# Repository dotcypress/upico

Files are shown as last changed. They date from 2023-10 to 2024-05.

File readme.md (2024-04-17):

## μPico

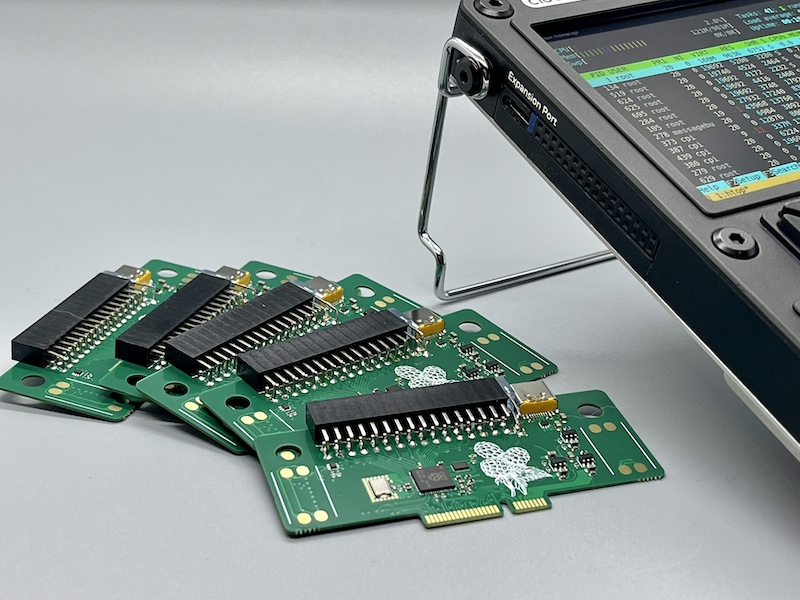
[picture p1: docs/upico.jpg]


### What is it?

uPico is a [RP2040](https://www.raspberrypi.com/products/rp2040/) powered expansion card designed to enhance the capabilities of [Clockwork's uConsole](https://www.clockworkpi.com/uconsole).

⚠️ Only R-01 and CM4 core are supported by control application.
Work in progress for A04/A06 core modules.

Second project name is `atto`, cause 10<sup>−6</sup> * 10<sup>-12</sup> = 10<sup>-18</sup> 🤓

### Features

* Internal Speakers Support
* Type-C (USB 2.0) port with programmable power switch and overcurrent protection
* 3.3V and 5V external power out with programmable switch and overcurrent protection
* RP2040 with extenal double-double PMOD compatible connector
* RP2040 controllable LED

## Resources

- [Schematics](docs/upico.pdf)
- [PCB Viewer](https://kicanvas.org/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)
- [Interactive BOM](https://htmlpreview.github.io/?https://github.com/dotcypress/upico/blob/main/docs/ibom.html)



### Control app installation

1. Download latest build from [Releases page](https://github.com/dotcypress/upico/releases)
2. Extract installer: `mkdir dist && tar -xzf upico_%version%.%core%.tar.gz -C dist`
3. Install: `cd dist && sudo ./install.sh`
4. Cleanup: `cd .. && rm -rf dist`
5. Print help: `upico help`

### Building control app from sources

1. Install rustup by following the instructions at https://rustup.rs
2. Clone this repo: `git clone git@github.com:dotcypress/upico.git && cd upico`
3. Build: `cargo build --release`
4. Install app: `sudo cp target/release/upico /usr/local/bin/`
5. Install service: `sudo cp upico.service /etc/systemd/system/`
6. Enable service: `sudo systemctl enable upico`
7. Start service: `sudo systemctl start upico`
8. Setup uPico extender USB device: `echo 'SUBSYSTEM=="usb",ATTRS{idVendor}=="1209",ATTRS{idProduct}=="bc07",MODE="0660",GROUP="plugdev"' > /etc/udev/rules.d/50-upico-permissions.rules`
9. Reload udev: `udevadm control --reload-rules`
10. Print help: `upico help`

### Flash firmware

1. `wget https://rptl.io/pico-blink`
2. `upico install pico-blink` or `upico install -m pico-blink` if automount is disabled for hot-plug devices.

See other examples: https://github.com/raspberrypi/pico-examples

### High level design diagram

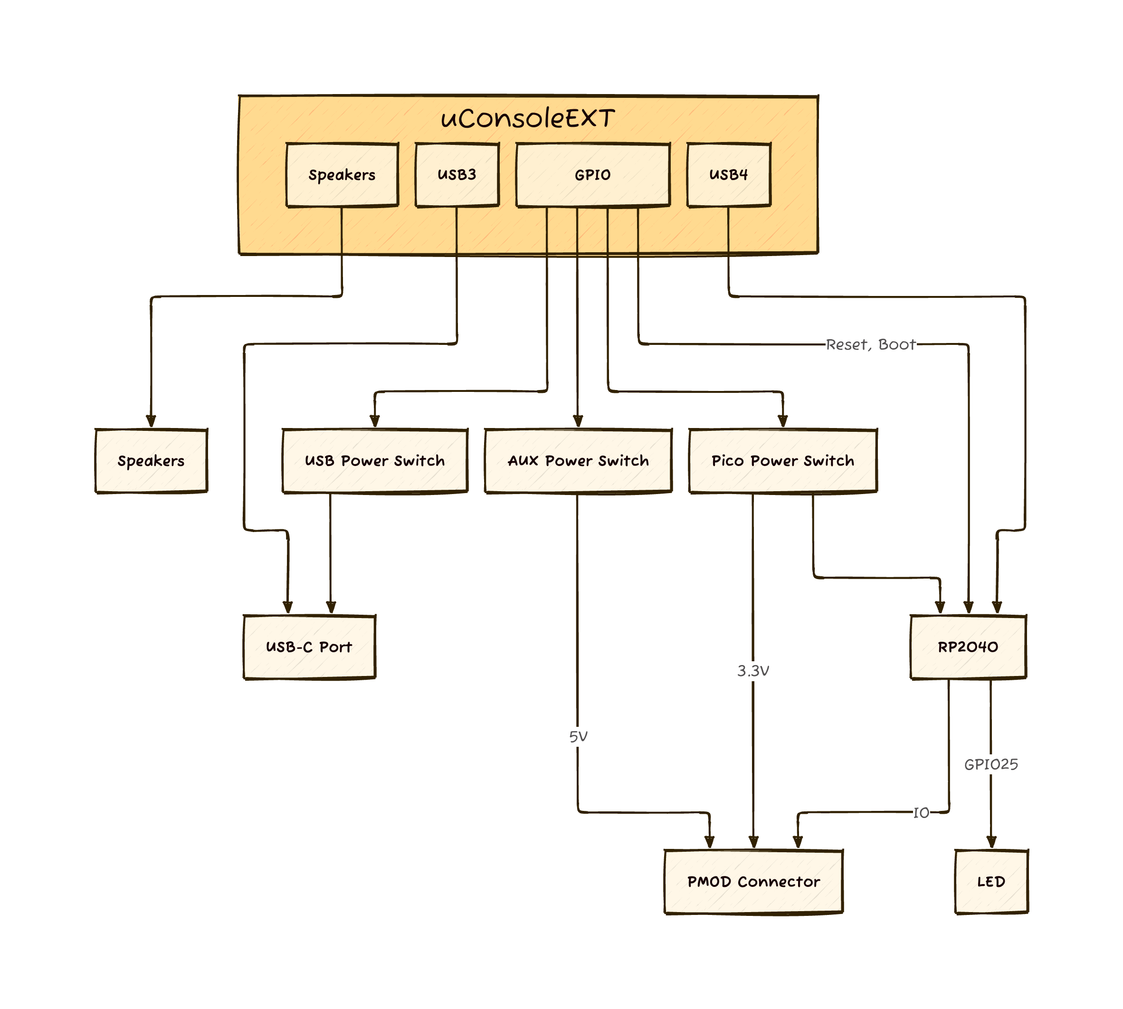
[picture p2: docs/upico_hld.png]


### GPIO Header Pinout
```
╔══════╦══════╗
║ AUX  ║ AUX  ║
╠══════╬══════╣
║ VDD  ║ VDD  ║
║ GND  ║ GND  ║
║ IO3  ║ IO7  ║
║ IO2  ║ IO6  ║
║ IO1  ║ IO5  ║
║ IO0  ║ IO4  ║
╠══════╬══════╣
║ IO27 ║ IO29 ║
║ IO26 ║ IO28 ║
║ IO18 ║ IO19 ║
╠══════╬══════╣
║ VDD  ║ VDD  ║
║ GND  ║ GND  ║
║ IO11 ║ IO15 ║
║ IO10 ║ IO14 ║
║ IO9  ║ IO13 ║
║ IO8  ║ IO12 ║
╚══════╩══════╝
```

## Errata

### CM4 core & uPico PCB rev:0x02

* Overcurrent reporting feature isn't supported.

## License

Licensed under either of

- Apache License, Version 2.0 ([LICENSE-APACHE](LICENSE-APACHE) or
  http://www.apache.org/licenses/LICENSE-2.0)
- MIT license ([LICENSE-MIT](LICENSE-MIT) or http://opensource.org/licenses/MIT)

at your option.

### Contribution

Unless you explicitly state otherwise, any contribution intentionally submitted
for inclusion in the work by you, as defined in the Apache-2.0 license, shall be
dual licensed as above, without any additional terms or conditions.

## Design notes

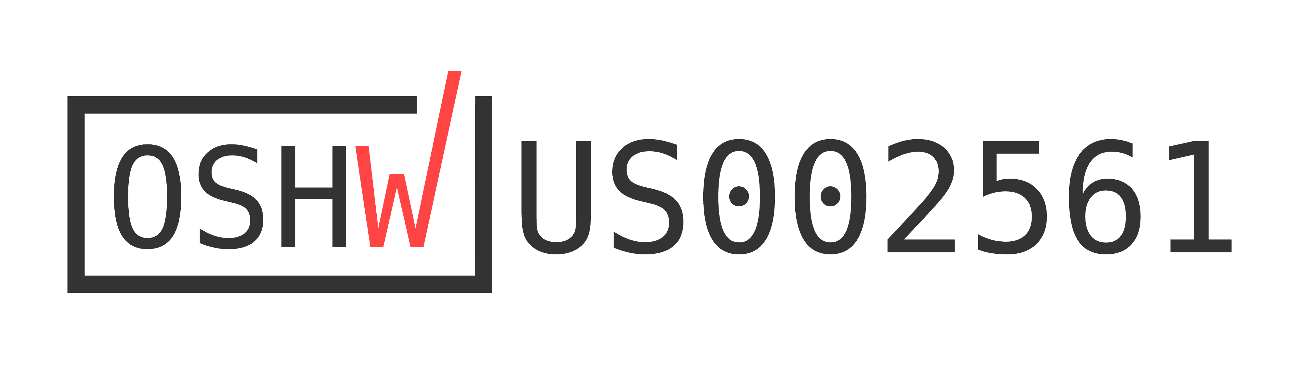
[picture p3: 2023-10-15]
docs/certification-mark-US002561.png

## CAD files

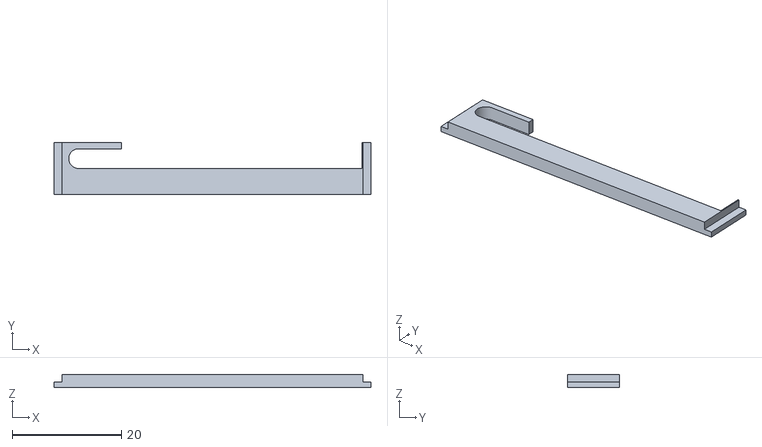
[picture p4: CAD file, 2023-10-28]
docs/cover.stl
58.0 x 9.50 x 2.40

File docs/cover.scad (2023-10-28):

$fn=128;
epsilon=0.01;

module cover() {
  difference() {
    union() {
      cube(size=[58, 9.5, 1], center=true);
      translate([0, 0, 1])
        cube(size=[55, 9.5, 1.8], center=true);
    }

    translate([5.3+epsilon, 2.5+epsilon, 0]) 
      cube(size=[44, 5, 20], center=true);

    translate([-24.5, 1.8, 0]) hull() {
      cylinder(r=1.8, h=20, center=true);
      translate([10, 0, 0])
        cylinder(r=1.8, h=20, center=true);
    }
  }
}

module print() {
  translate([0, 4, 0.5]) 
    cube(size=[1, 88, 1], center=true);
  for (i=[-3:4]) {
    translate([0, i*12, 0.6]) cover();
  }
}

// print();
cover();

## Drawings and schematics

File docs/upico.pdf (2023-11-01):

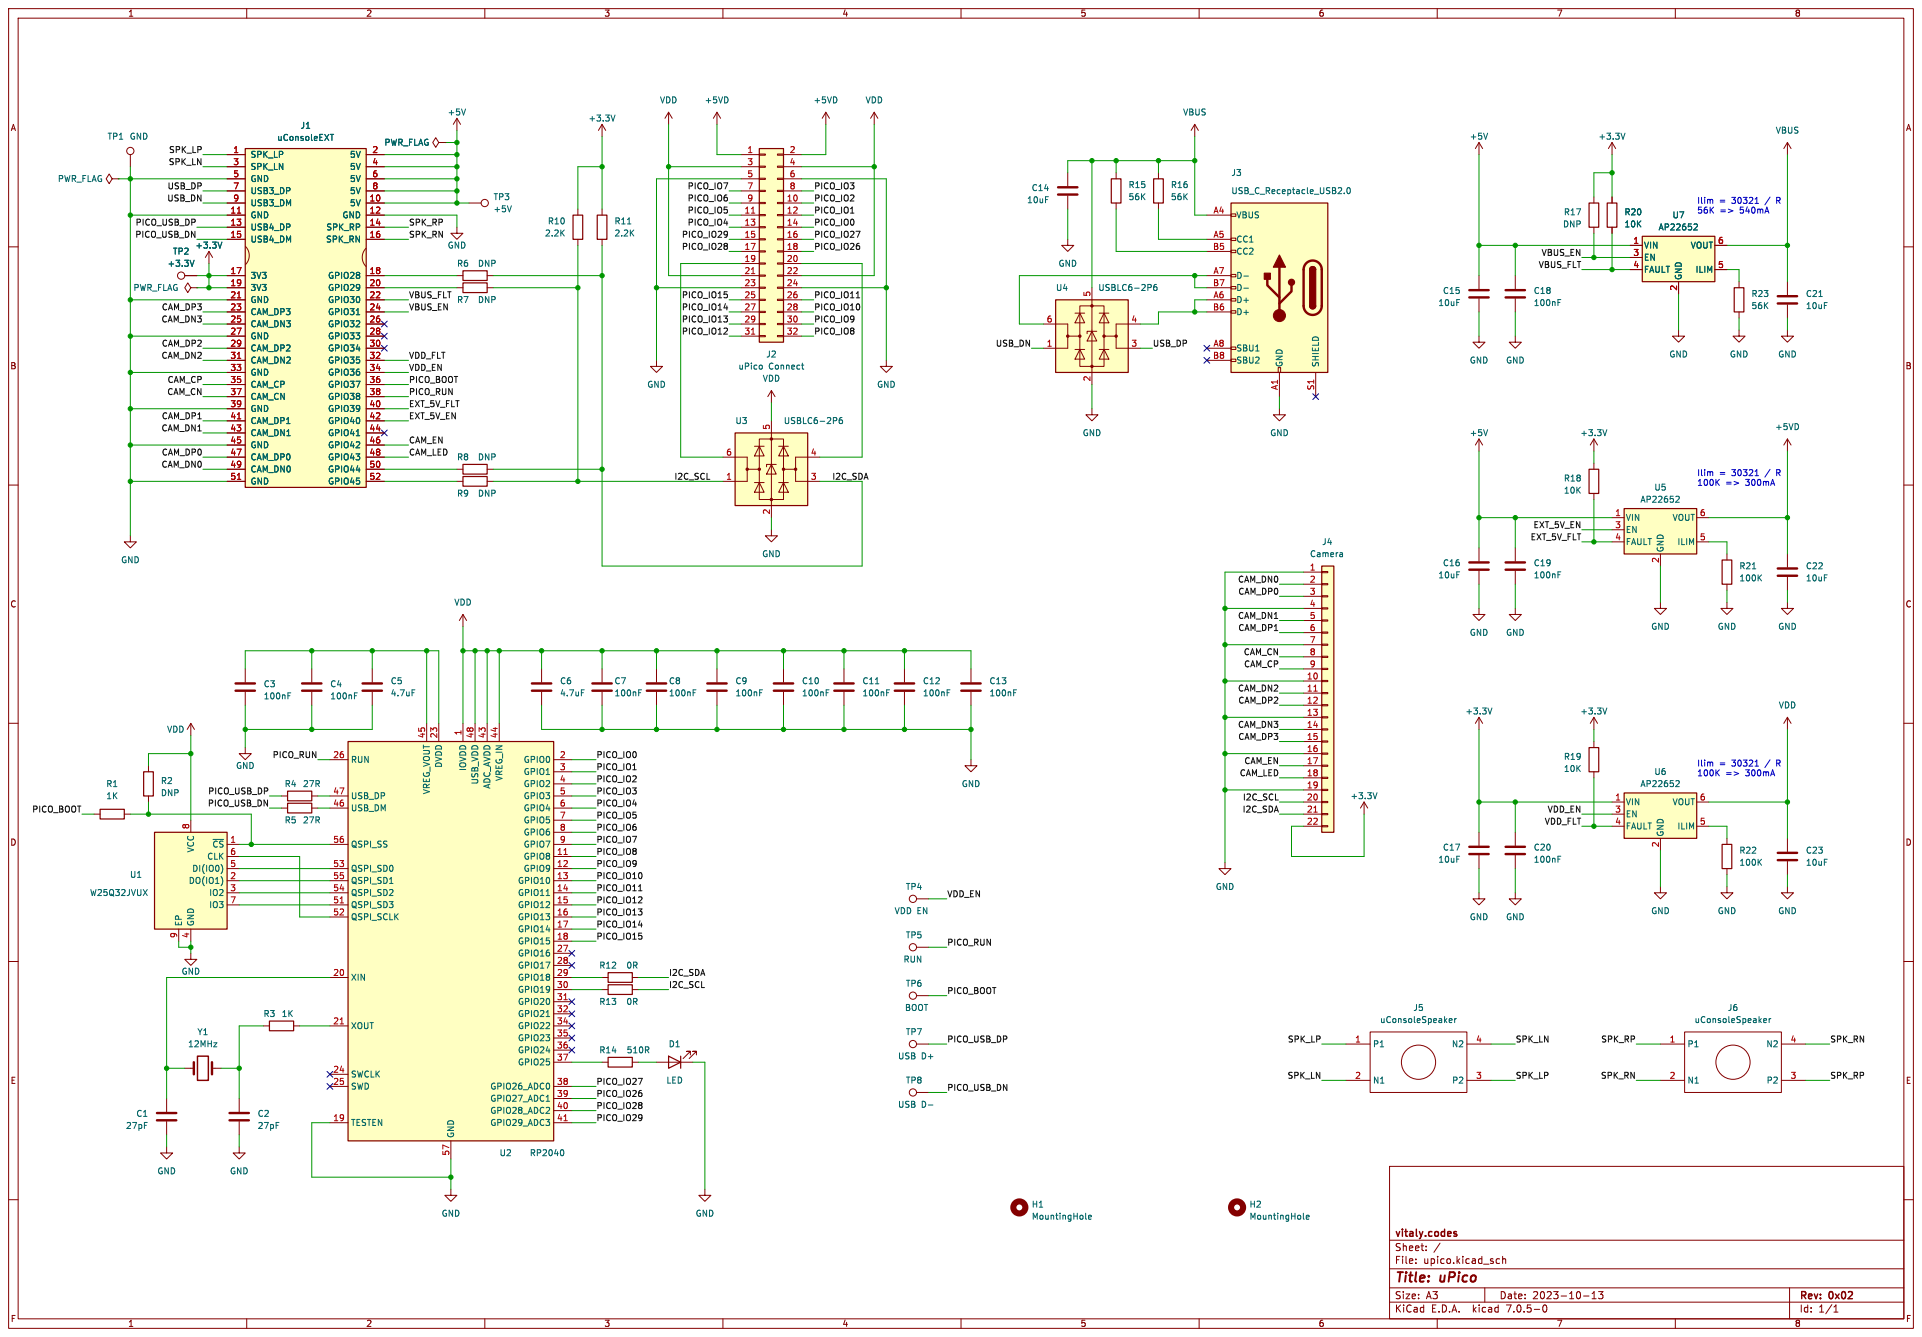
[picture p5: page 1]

1 GPIO8 11 GPIO9 12 GPIO10 13 GPIO11 14 GPIO12 15 GPIO13 16 GPIO14 17 GPIO15 18 TESTEN 19 GPIO0 2 XIN 20 XOUT 21 DVDD 23 SWCLK 24 SWD 25 RUN 26 GPIO16 27 GPIO17 28 GPIO18 29 GPIO1 3 GPIO19 30 GPIO20 31 GPIO21 32 GPIO22 34 GPIO23 35 GPIO24 36 GPIO25 37 GPIO26_ADC0 38 GPIO27_ADC1 39 GPIO2 4 GPIO28_ADC2 40 GPIO29_ADC3 41 ADC_AVDD 43 VREG_IN 44 VREG_VOUT 45 USB_DM 46 USB_DP 47 USB_VDD 48 GPIO3 5 QSPI_SD3 51 QSPI_SCLK 52 QSPI_SD0 53 QSPI_SD2 54 QSPI_SD1 55 QSPI_SS 56 GND 57 GPIO4 6 GPIO5 7 GPIO6 8 GPIO7 9 U2 RP2040

H1 MountingHole TP7 USB D+ TP8 USB D- TP5 RUN

File: upico.kicad_sch Sheet: / vitaly.codes

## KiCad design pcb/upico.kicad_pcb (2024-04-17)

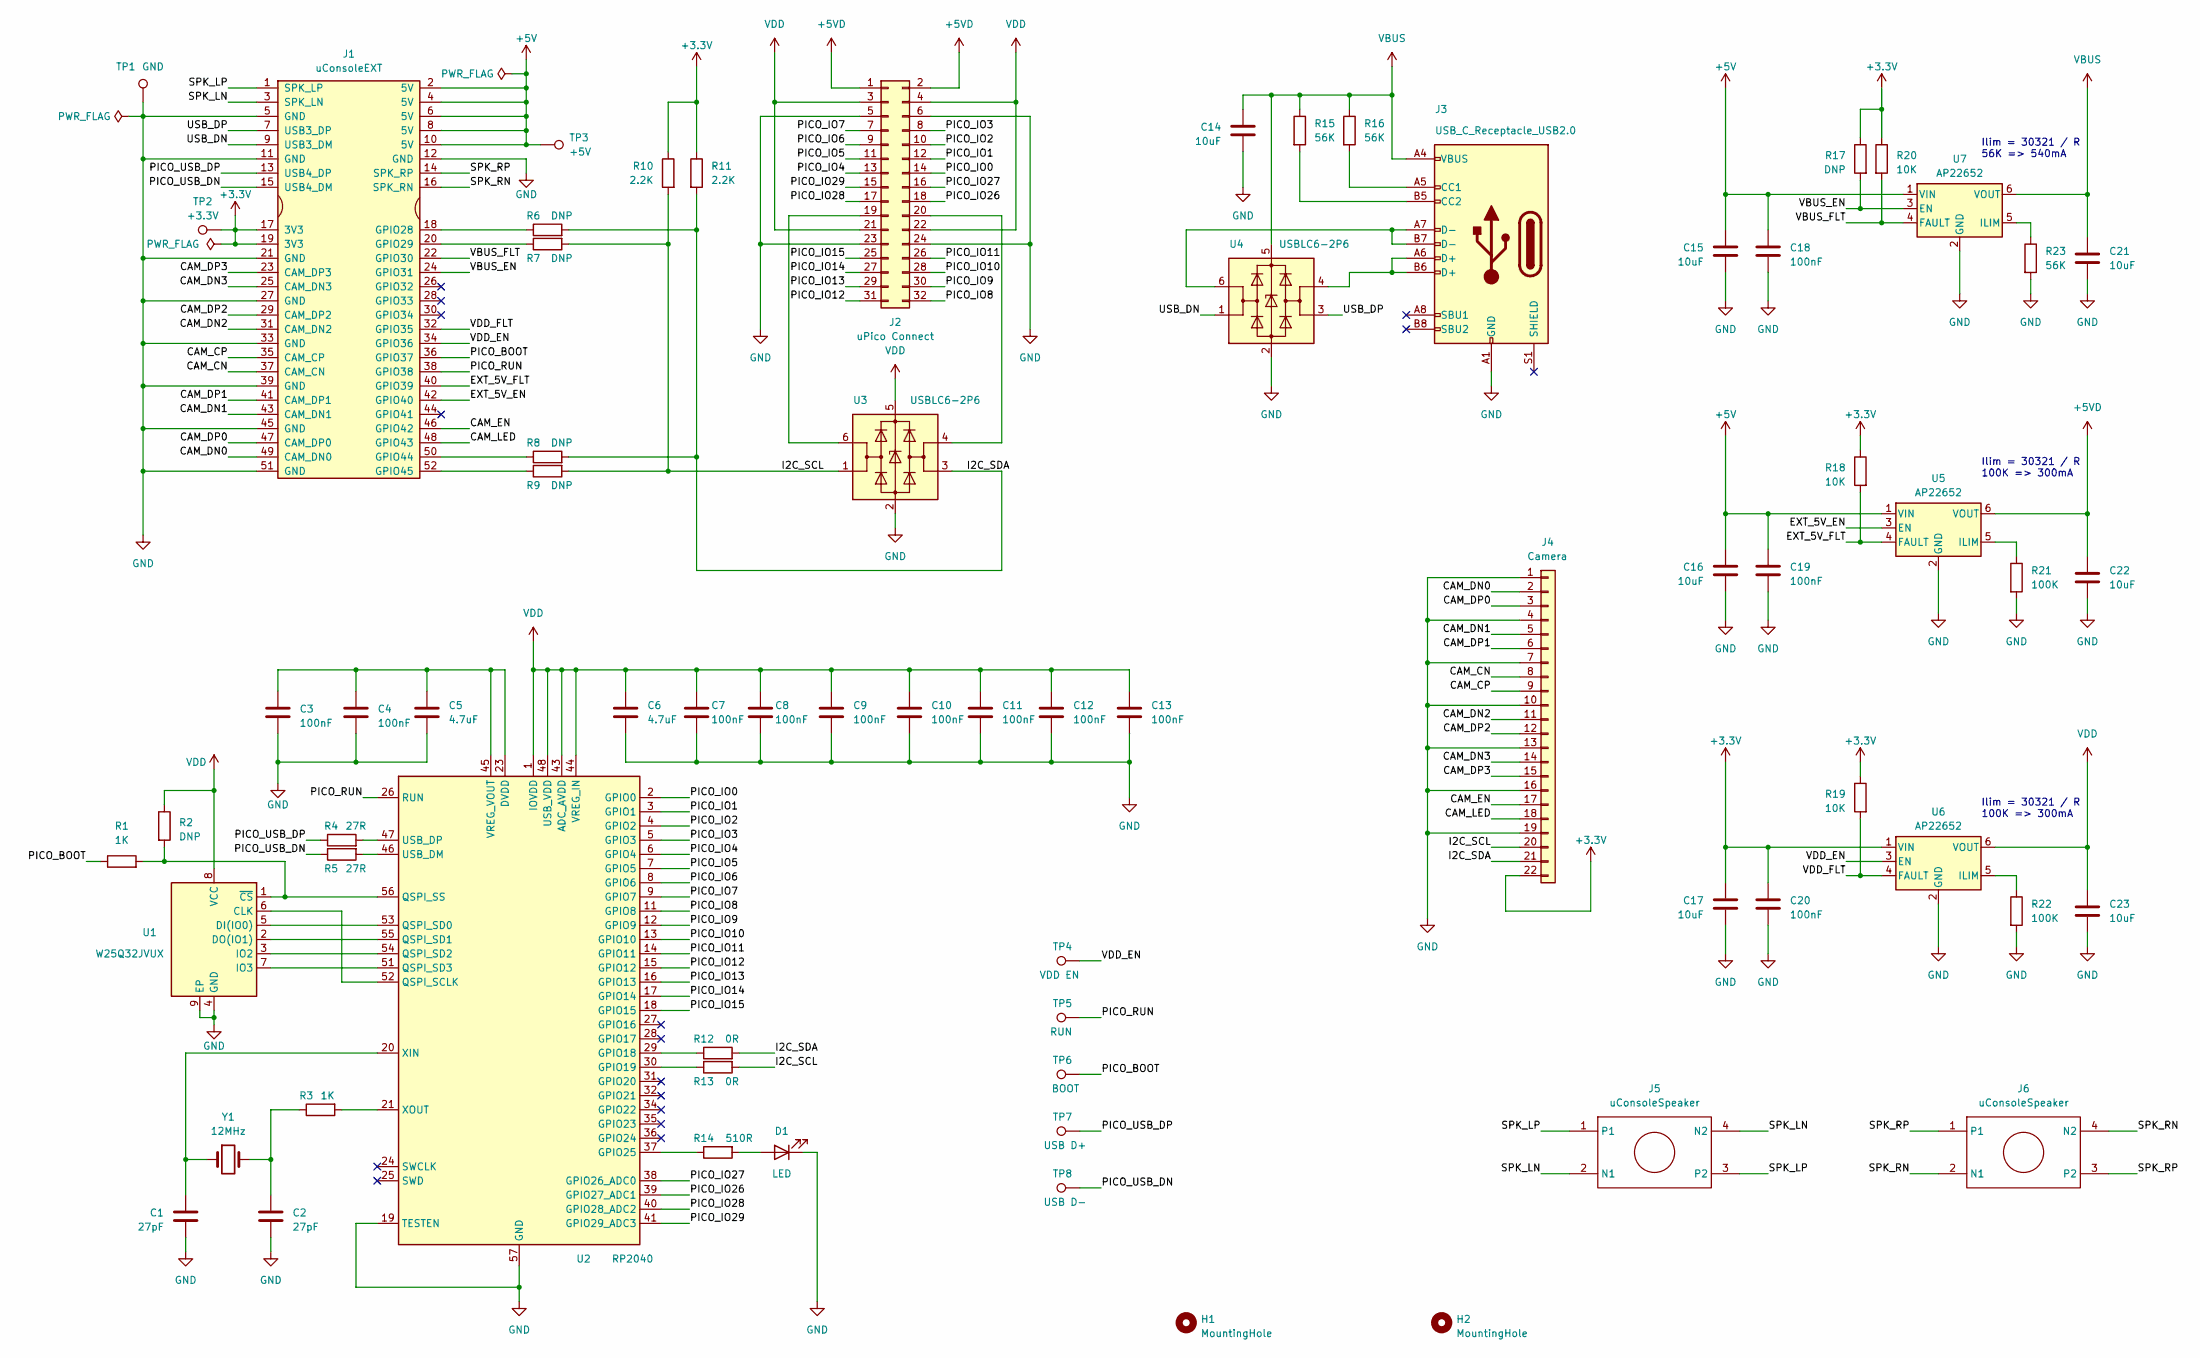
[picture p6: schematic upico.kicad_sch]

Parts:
C1, C2: 27pF; C_0402_1005Metric
C3, C4, C7, C8, C9, C10, C11, C12, C13, C18, C19, C20: 100nF; C_0402_1005Metric
C5, C6: 4.7uF; C_0402_1005Metric
C14, C15, C16, C17, C21, C22, C23: 10uF; C_0603_1608Metric
D1: LED; LED_SideEmitter_Rectangular_W4.5mm_H1.6mm
H1, H2: MountingHole; MountingHole_5.3mm_M5
J1: uConsoleEXT; ext
J2: uPico Connect; PinSocket_2x16_P2.54mm_Horizontal
J3: USB_C_Receptacle_USB2.0; USB_C_Receptacle_HRO_TYPE-C-31-M-12
J4: Camera; Hirose_FH12-22S-0.5SH_1x22-1MP_P0.50mm_Horizontal
J5, J6: uConsoleSpeaker; speaker
R1, R3: 1K; R_0402_1005Metric
R2, R6, R7, R8, R9, R17: DNP; R_0402_1005Metric
R4, R5: 27R; R_0402_1005Metric
R10, R11: 2.2K; R_0402_1005Metric
R12, R13: 0R; R_0402_1005Metric
R14: 510R; R_0402_1005Metric
R15, R16, R23: 56K; R_0402_1005Metric
R18, R19, R20: 10K; R_0402_1005Metric
R21, R22: 100K; R_0402_1005Metric
TP1: GND; TestPoint_Pad_D1.0mm
TP2: +3.3V; TestPoint_Pad_D1.0mm
TP3: +5V; TestPoint_Pad_D1.0mm
TP4: VDD EN; TestPoint_Pad_D1.0mm
TP5: RUN; TestPoint_Pad_D1.0mm
TP6: BOOT; TestPoint_Pad_D1.0mm
TP7: USB D+; TestPoint_Pad_D1.0mm
TP8: USB D-; TestPoint_Pad_D1.0mm
U1: W25Q32JVUX; USON-8_2x3mm_P0.5mm
U2: RP2040; QFN-56-1EP_7x7mm_P0.4mm_EP3.2x3.2mm
U3, U4: USBLC6-2P6; SOT-666
U5, U6, U7: AP22652; SOT-23-6
Y1: 12MHz; Crystal_SMD_5032-2Pin_5.0x3.2mm

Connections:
+3.3V: C17.2, C20.2, J1.17 (3V3), J1.19 (3V3), J4.22, R10.1, R11.1, R17.1, R18.1, R19.1, R20.1, TP2.1, U6.1 (VIN)
+5V: C15.2, C16.2, C18.2, C19.2, J1.2 (5V), J1.4 (5V), J1.6 (5V), J1.8 (5V), J1.10 (5V), TP3.1, U5.1 (VIN), U7.1 (VIN)
+5VD: C22.1, J2.1, J2.2, U5.6 (VOUT)
/CAM_CN: J1.37 (CAM_CN), J4.8
/CAM_CP: J1.35 (CAM_CP), J4.9
/CAM_DN0: J1.49 (CAM_DN0), J4.2
/CAM_DN1: J1.43 (CAM_DN1), J4.5
/CAM_DN2: J1.31 (CAM_DN2), J4.11
/CAM_DN3: J1.25 (CAM_DN3), J4.14
/CAM_DP0: J1.47 (CAM_DP0), J4.3
/CAM_DP1: J1.41 (CAM_DP1), J4.6
/CAM_DP2: J1.29 (CAM_DP2), J4.12
/CAM_DP3: J1.23 (CAM_DP3), J4.15
/CAM_EN: J1.46 (GPIO42), J4.17
/CAM_LED: J1.48 (GPIO43), J4.18
/EXT_5V_EN: J1.42 (GPIO40), U5.3 (EN)
/EXT_5V_FLT: J1.40 (GPIO39), R18.2, U5.4 (FAULT)
/I2C_SCL: J4.20, R7.2, R9.2, R10.2, R13.2, U3.1 (I/O1)
/I2C_SDA: J4.21, R6.2, R8.2, R11.2, R12.2, U3.3 (I/O2)
/PICO_BOOT: J1.36 (GPIO37), R1.1, TP6.1
/PICO_IO0: J2.14, U2.2 (GPIO0)
/PICO_IO1: J2.12, U2.3 (GPIO1)
/PICO_IO2: J2.10, U2.4 (GPIO2)
/PICO_IO3: J2.8, U2.5 (GPIO3)
/PICO_IO4: J2.13, U2.6 (GPIO4)
/PICO_IO5: J2.11, U2.7 (GPIO5)
/PICO_IO6: J2.9, U2.8 (GPIO6)
/PICO_IO7: J2.7, U2.9 (GPIO7)
/PICO_IO8: J2.32, U2.11 (GPIO8)
/PICO_IO9: J2.30, U2.12 (GPIO9)
/PICO_IO10: J2.28, U2.13 (GPIO10)
/PICO_IO11: J2.26, U2.14 (GPIO11)
/PICO_IO12: J2.31, U2.15 (GPIO12)
/PICO_IO13: J2.29, U2.16 (GPIO13)
/PICO_IO14: J2.27, U2.17 (GPIO14)
/PICO_IO15: J2.25, U2.18 (GPIO15)
/PICO_IO26: J2.18, U2.39 (GPIO27_ADC1)
/PICO_IO27: J2.16, U2.38 (GPIO26_ADC0)
/PICO_IO28: J2.17, U2.40 (GPIO28_ADC2)
/PICO_IO29: J2.15, U2.41 (GPIO29_ADC3)
/PICO_RUN: J1.38 (GPIO38), TP5.1, U2.26 (RUN)
/PICO_USB_DN: J1.15 (USB4_DM), R5.1, TP8.1
/PICO_USB_DP: J1.13 (USB4_DP), R4.1, TP7.1
/SPK_LN: J1.3 (SPK_LN), J5.2 (N1), J5.4 (N2)
/SPK_LP: J1.1 (SPK_LP), J5.1, J5.3 (P2)
/SPK_RN: J1.16 (SPK_RN), J6.2 (N1), J6.4 (N2)
/SPK_RP: J1.14 (SPK_RP), J6.1, J6.3 (P2)
/USB_DN: J1.9 (USB3_DM), U4.1 (I/O1)
/USB_DP: J1.7 (USB3_DP), U4.3 (I/O2)
/VBUS_EN: J1.24 (GPIO31), R17.2, U7.3 (EN)
/VBUS_FLT: J1.22 (GPIO30), R20.2, U7.4 (FAULT)
/VDD_EN: J1.34 (GPIO36), TP4.1, U6.3 (EN)
/VDD_FLT: J1.32 (GPIO35), R19.2, U6.4 (FAULT)
GND: C1.2, C2.2, C3.2, C4.2, C5.2, C6.2, C7.2, C8.2, C9.2, C10.2, C11.2, C12.2, C13.2, C14.1, C15.1, C16.1, C17.1, C18.1, C19.1, C20.1, C21.2, C22.2, C23.2, D1.1 (K), J1.5 (GND), J1.11 (GND), J1.12 (GND), J1.21 (GND), J1.27 (GND), J1.33 (GND), J1.39 (GND), J1.45 (GND), J1.51 (GND), J2.5, J2.6, J2.23, J2.24, J3.A1 (GND), J3.A12 (GND), J3.B1 (GND), J3.B12 (GND), J4.1, J4.4, J4.7, J4.10, J4.13, J4.16, J4.19, R21.2, R22.2, R23.2, TP1.1, U1.4 (GND), U1.9 (EP), U2.19 (TESTEN), U2.57 (GND), U3.2 (GND), U4.2 (GND), U5.2 (GND), U6.2 (GND), U7.2 (GND)
unnamed: C2.1, R3.1, Y1.2
unnamed: D1.2 (A), R14.2
unnamed: J1.18 (GPIO28), R6.1
unnamed: J1.20 (GPIO29), R7.1
unnamed: J1.50 (GPIO44), R8.1
unnamed: J1.52 (GPIO45), R9.1
unnamed: J2.19, U3.6 (I/O1)
unnamed: J2.20, U3.4 (I/O2)
unnamed: J3.A5 (CC1), R16.2
unnamed: J3.B5 (CC2), R15.2
unnamed: J3.A6 (D+), J3.B6 (D+), U4.4 (I/O2)
unnamed: J3.A7 (D-), J3.B7 (D-), U4.6 (I/O1)
unnamed: U1.6 (CLK), U2.52 (QSPI_SCLK)
unnamed: U1.5 (DI(IO0)), U2.53 (QSPI_SD0)
unnamed: U1.2 (DO(IO1)), U2.55 (QSPI_SD1)
unnamed: U1.3 (IO2), U2.54 (QSPI_SD2)
unnamed: U1.7 (IO3), U2.51 (QSPI_SD3)
unnamed: R1.2, R2.2, U1.1 (~CS), U2.56 (QSPI_SS)
unnamed: R12.1, U2.29 (GPIO18)
unnamed: R13.1, U2.30 (GPIO19)
unnamed: R14.1, U2.37 (GPIO25)
unnamed: R5.2, U2.46 (USB_DM)
unnamed: R4.2, U2.47 (USB_DP)
unnamed: C3.1, C4.1, C5.1, U2.23 (DVDD), U2.45 (VREG_VOUT), U2.50 (DVDD)
unnamed: C1.1, U2.20 (XIN), Y1.1
unnamed: R3.2, U2.21 (XOUT)
unnamed: R21.1, U5.5 (ILIM)
unnamed: R22.1, U6.5 (ILIM)
unnamed: R23.1, U7.5 (ILIM)
VBUS: C14.2, C21.1, J3.A4 (VBUS), J3.A9 (VBUS), J3.B4 (VBUS), J3.B9 (VBUS), R15.1, R16.1, U4.5 (VBUS), U7.6 (VOUT)
VDD: C6.1, C7.1, C8.1, C9.1, C10.1, C11.1, C12.1, C13.1, C23.1, J2.3, J2.4, J2.21, J2.22, R2.1, U1.8 (VCC), U2.1 (IOVDD), U2.10 (IOVDD), U2.22 (IOVDD), U2.33 (IOVDD), U2.42 (IOVDD), U2.43 (ADC_AVDD), U2.44 (VREG_IN), U2.48 (USB_VDD), U2.49 (IOVDD), U3.5 (VBUS), U6.6 (VOUT)

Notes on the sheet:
Ilim = 30321 / R 56K => 540mA
Ilim = 30321 / R 100K => 300mA

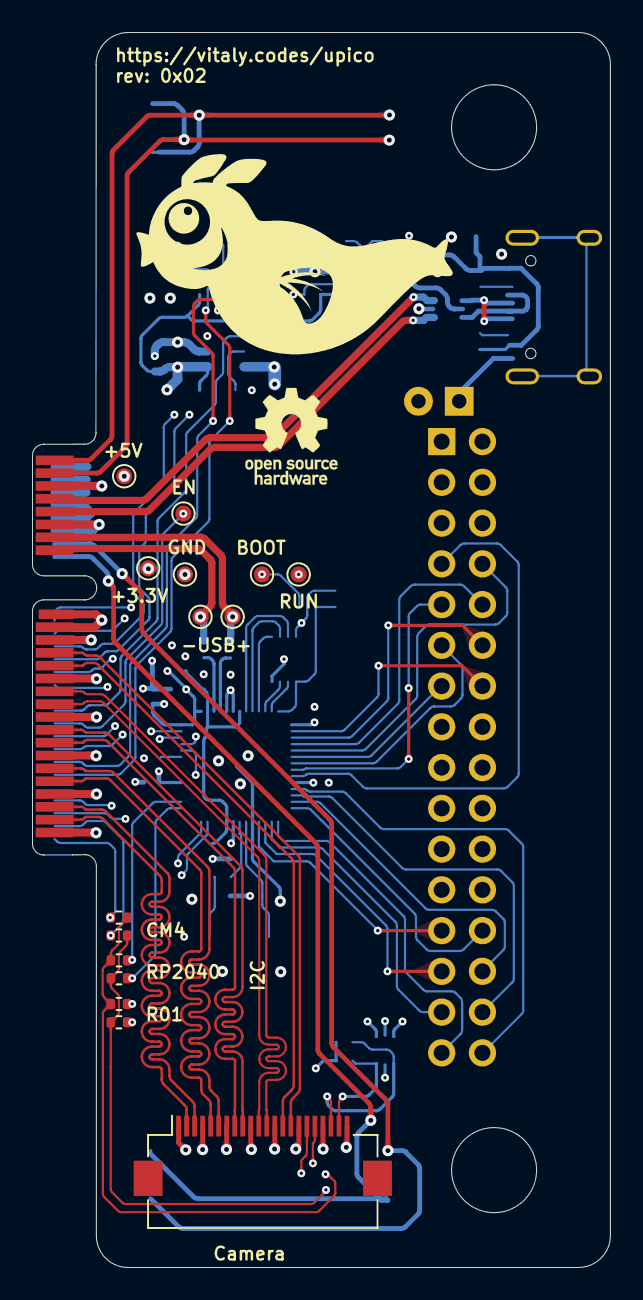
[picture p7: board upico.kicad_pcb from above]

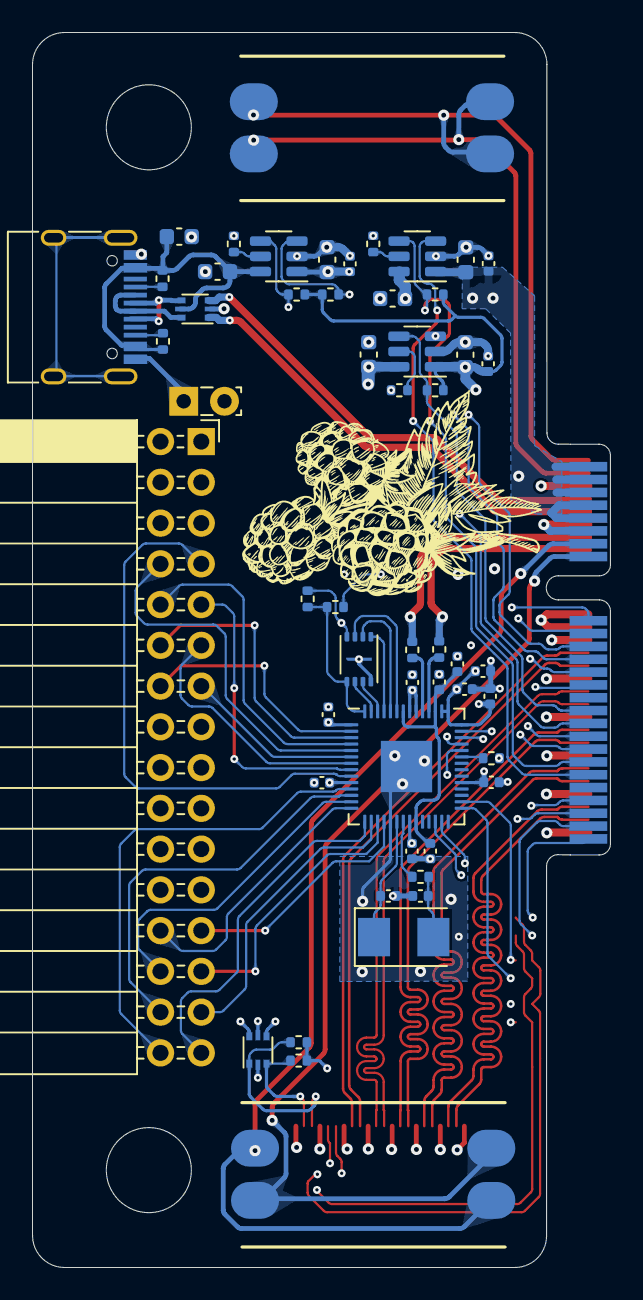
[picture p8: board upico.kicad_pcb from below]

Board: 6 copper layers, 36.0 x 77.0 mm, 71 parts (53 on the bottom side), 85 nets.

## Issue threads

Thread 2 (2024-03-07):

Internal GPIO headers?

madeofstown, 2024-03-07:
I'm sure there have to be others who would like to have an internal GPIO connection on the uPico for connecting small expansion boards that would fit inside the uConsole.

Just wanted to see if there is work being done on a new version and if others would be interested in internal GPIO pins.

I realize I could modify the board myself but I would need to learn to solder or PCB design, both are things that scare me.

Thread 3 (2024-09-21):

What is the correct thickness of the pcb

nullbeing, 2024-09-21:
I ordered the pcb with 1.6mm thick and it doesn't work
What is the correct thickness of the pcb? 1mm?

dotcypress, 2024-09-29:
@nullbeing correct thickness is 0.8mm

nullbeing, 2024-10-08:
> @nullbeing correct thickness is 0.8mm

Thank you very much indeed for your help, I will try 0.8mm

Closed 2025-04-12.

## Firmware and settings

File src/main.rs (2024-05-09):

use clap::{builder::PossibleValue, *};
use clap_complete::{generate, Shell};
use config::*;
use extender::*;
use gpio::*;
use service::*;
use std::path::Path;
use std::time::Duration;
use std::*;

mod config;
mod extender;
mod gpio;
mod service;

#[derive(Debug)]
pub enum AppError {
    InvalidLine,
    InvalidGpioLine,
    InvalidAdcChannel,
    InvalidLedMode,
    MountFailed,
    IoError(io::Error),
    ServiceError(io::Error),
    GpioError(io::Error),
    DecodeError(string::FromUtf8Error),
    ParseIntError(num::ParseIntError),
    ProtocolError(rmp_serde::decode::Error),
    UsbError(rusb::Error),
}

pub type AppResult = Result<(), AppError>;

fn main() {
    if let Err(err) = run() {
        match err {
            AppError::InvalidLine => println!("Invalid power line name"),
            AppError::InvalidAdcChannel => println!("Invalid ADC channel"),
            AppError::InvalidLedMode => println!("Invalid LED mode"),
            AppError::InvalidGpioLine => println!("Invalid GPIO number"),
            AppError::MountFailed => println!("Failed to mount Pico drive"),
            AppError::GpioError(err) => println!("GPIO error: {}", err),
            AppError::IoError(err) => println!("IO error: {}", err),
            AppError::ServiceError(err) => println!("Service error: {}", err),
            AppError::DecodeError(err) => println!("Decode error: {}", err),
            AppError::ProtocolError(err) => println!("Protocol error: {}", err),
            AppError::UsbError(rusb::Error::NoDevice) => println!("Pico extender not found.\nCommand for flashing extender firmware: \"upico gpio install\"."),
            AppError::UsbError(err) => println!("USB error: {}", err),
            AppError::ParseIntError(err) => println!("Parse error: {}", err),
        };
    }
}

fn cli() -> Command {
    let mount_arg = arg!(mount: -m "Mount Pico disk");
    let dev_arg = arg!(-d <PICO_DEV> "Path to Pico disk device").default_value("/dev/sda1");
    let line_arg = arg!(<LINE> "Power line").required(true);
    let line_arg = if platform::AUX_SWITCH {
        line_arg.value_parser([
            PossibleValue::new("aux"),
            PossibleValue::new("vdd"),
            PossibleValue::new("usb"),
        ])
    } else {
        line_arg.value_parser([PossibleValue::new("vdd"), PossibleValue::new("usb")])
    };

    let mount_path: &'static str = {
        let username = env::var("USER").unwrap_or("pi".into());
        Box::leak(format!("/media/{username}/RPI-RP2").into_boxed_str())
    };

    Command::new("upico")
        .about("uPico control app")
        .version(env!("CARGO_PKG_VERSION"))
        .author(env!("CARGO_PKG_AUTHORS"))
        .subcommand_required(true)
        .arg_required_else_help(true)
        .subcommand(Command::new("service").about("Start service").hide(true))
        .subcommand(Command::new("reset").about("Reset Pico"))
        .subcommand(
            Command::new("boot")
                .arg(mount_arg.clone())
                .arg(dev_arg.clone())
                .about("Reset Pico and enter USB bootloader"),
        )
        .subcommand(
            Command::new("generate")
                .arg(
                    Arg::new("generator")
                        .required(true)
                        .value_parser(value_parser!(Shell)),
                )
                .about("Generate shell completions"),
        )
        .subcommand(
            Command::new("gpio")
                .about("GPIO utils")
                .subcommand_required(true)
                .arg_required_else_help(true)
                .subcommand(
                    Command::new("get")
                        .arg(arg!([PIN] "GPIO pin number (0-15)."))
                        .about("Print GPIO status"),
                )
                .subcommand(
                    Command::new("set")
                        .arg(
                            arg!(<CONFIG> "Comma separated GPIO config (0=1,3=0,7=i,..).")
                                .value_delimiter(',')
                                .required(true),
                        )
                        .about("Set GPIO config"),
                )
                .subcommand(
                    Command::new("led")
                        .arg(arg!(<STATUS> "LED status (on, off).").required(true))
                        .about("Set LED status"),
                )
                .subcommand(
                    Command::new("install")
                        .arg(
                            arg!(-p <PICO_PATH> "Path to mounted Pico disk")
                                .default_value(mount_path),
                        )
                        .arg(mount_arg.clone())
                        .arg(dev_arg.clone())
                        .about("Install GPIO extender firmware to Pico"),
                ),
        )
        .subcommand(
            Command::new("install")
                .about("Install firmware to Pico")
                .arg_required_else_help(true)
                .arg(arg!(<FIRMWARE> "Path to UF2 firmware file").required(true))
                .arg(arg!(-p <PICO_PATH> "Path to mounted Pico disk").default_value(mount_path))
                .arg(mount_arg)
                .arg(dev_arg),
        )
        .subcommand(
            Command::new("power")
                .about("Power management")
                .subcommand_required(true)
                .arg_required_else_help(true)
                .subcommand(Command::new("on").about("Power on").arg(line_arg.clone()))
                .subcommand(Command::new("off").about("Power off").arg(line_arg.clone()))
                .subcommand(Command::new("cycle").about("Power cycle").arg(line_arg))
                .subcommand(
                    Command::new("status")
                        .about("Print power status")
                        .hide(!platform::OCP_REPORTING),
                ),
        )
        .subcommand(
            Command::new("pinout")
                .arg(arg!(full: -f "Print pin functions"))
                .about("Print pinout diagram"),
        )
}

fn print_power_state(line: &str, state: PowerState) {
    println!(
        "{line}:  {} {}",
        if state.on { "ON " } else { "OFF" },
        if platform::OCP_REPORTING && state.ocp {
            "[OCP]"
        } else {
            ""
        }
    );
}

fn parse_power_line(args: &ArgMatches) -> Result<PowerLine, AppError> {
    args.get_one::<String>("LINE")
        .unwrap()
        .try_into()
        .map_err(|_| AppError::InvalidLine)
}

fn sleep(millis: u64) {
    thread::sleep(Duration::from_millis(millis));
}

fn wait_for_path(path: &Path) {
    for _ in 0..100 {
        if path.exists() {
            sleep(200);
            break;
        }
        sleep(100);
    }
}

fn mount_pico(disk: &str) -> Result<String, AppError> {
    wait_for_path(Path::new(disk));
    for _ in 0..50 {
        if let Ok(output) = process::Command::new("udisksctl")
            .args(["mount", "-b", disk])
            .stdout(process::Stdio::piped())
            .output()
        {
            if output.status.success() {
                let res = String::from_utf8(output.stdout).map_err(AppError::DecodeError)?;
                return res
                    .split(" at ")
                    .last()
                    .map(|s| s.trim().to_owned())
                    .ok_or(AppError::MountFailed);
            }
            sleep(100);
        }
    }
    Err(AppError::MountFailed)
}

fn run() -> AppResult {
    match cli().get_matches().subcommand() {
        Some(("service", _)) => Service::start()?,
        Some(("generate", args)) => {
            if let Some(generator) = args.get_one::<Shell>("generator") {
                generate(*generator, &mut cli(), "upico", &mut io::stdout());
            }
        }
        Some(("pinout", args)) => {
            if args.get_flag("full") {
                println!("{}", include_str!("resources/pinout_full.ansi"));
            } else {
                println!("{}", include_str!("resources/pinout.ansi"));
            }
        }
        Some(("reset", _)) => {
            Service::send(Request::Reset)?;
        }
        Some(("boot", args)) => {
            Service::send(Request::EnterBootloader)?;
            if args.get_flag("mount") {
                let disk = args.get_one::<String>("PICO_DEV").unwrap();
                mount_pico(disk)?;
            }
        }
        Some(("install", args)) => {
            Service::send(Request::EnterBootloader)?;
            let mut path = if args.get_flag("mount") {
                let disk = args.get_one::<String>("PICO_DEV").unwrap();
                mount_pico(disk)?
            } else {
                let path = args.get_one::<String>("PICO_PATH").unwrap().to_string();
                wait_for_path(Path::new(&path));
                path
            };
            path.push_str("/fw.uf2");
            let firmware = args.get_one::<String>("FIRMWARE").unwrap();
            fs::copy(firmware, path).map_err(AppError::IoError)?;
        }
        Some(("power", args)) => match args.subcommand() {
            Some(("on", args)) => {
                let line = parse_power_line(args)?;
                Service::send(Request::PowerOn(line))?;
            }
            Some(("off", args)) => {
                let line = parse_power_line(args)?;
                Service::send(Request::PowerOff(line))?;
            }
            Some(("cycle", args)) => {
                let line = parse_power_line(args)?;
                Service::send(Request::PowerCycle(line))?;
            }
            Some(("status", _)) => {
                if let Response::PowerReport(report) = Service::send(Request::PowerStatus)? {
                    if platform::AUX_SWITCH {
                        print_power_state("AUX", report.aux);
                    }
                    print_power_state("VDD", report.vdd);
                    print_power_state("USB", report.usb);
                }
            }
            _ => {}
        },
        Some(("gpio", args)) => match args.subcommand() {
            Some(("set", args)) => {
                let mut gpio_state = Extender::read_digital().map_err(AppError::UsbError)?;
                if let Some(configs) = args.get_many::<String>("CONFIG") {
                    for pin_config in configs {
                        if let Some((pin, mode)) = pin_config.split_once('=') {
                            let pin: u8 = pin.parse().map_err(AppError::ParseIntError)?;
                            if pin >= 16 {
                                return Err(AppError::InvalidGpioLine);
                            }
                            match mode {
                                "i" => gpio_state.set_mode(pin, false),
                                "0" => {
                                    gpio_state.set_mode(pin, true);
                                    gpio_state.set_level(pin, false);
                                }
                                "1" => {
                                    gpio_state.set_mode(pin, true);
                                    gpio_state.set_level(pin, true);
                                }
                                _ => {}
                            }
                        }
                    }
                }
                Extender::write_digital(gpio_state).map_err(AppError::UsbError)?;
            }
            Some(("get", args)) => {
                if let Some(pin) = args
                    .get_one::<String>("PIN")
                    .map(|s| s.parse::<u8>().unwrap_or_default())
                {
                    match pin {
                        0..=15 => {
                            let gpio_state =
                                Extender::read_digital().map_err(AppError::UsbError)?;
                            let level = if gpio_state.get_level(pin) { "1" } else { "0" };
                            println!("{}", level);
                        }
                        26..=29 => {
                            let values = Extender::read_analog().map_err(AppError::UsbError)?;
                            println!("{}", values[pin as usize - 26]);
                        }
                        _ => return Err(AppError::InvalidGpioLine),
                    }
                } else {
                    let gpio_state = Extender::read_digital().map_err(AppError::UsbError)?;
                    for pin in 0..16 {
                        let level = if gpio_state.get_level(pin) { "1" } else { "0" };
                        let mode = if gpio_state.get_mode(pin) {
                            "Output"
                        } else {
                            "Input"
                        };
                        println!("GPIO{}\t{}\t{}", pin, mode, level);
                    }
                    let values = Extender::read_analog().map_err(AppError::UsbError)?;
                    for (idx, val) in values.iter().enumerate() {
                        println!("GPIO{}\tAnalog\t{}", idx + 26, val);
                    }
                }
            }
            Some(("led", args)) => match args.get_one::<String>("STATUS") {
                Some(status) => match status.as_str() {
                    "on" => Extender::set_led(true).map_err(AppError::UsbError)?,
                    "off" => Extender::set_led(false).map_err(AppError::UsbError)?,
                    _ => return Err(AppError::InvalidLedMode),
                },
                _ => return Err(AppError::InvalidLedMode),
            },

            Some(("install", args)) => {
                Service::send(Request::EnterBootloader)?;
                let mut path = if args.get_flag("mount") {
                    let disk = args.get_one::<String>("PICO_DEV").unwrap();
                    mount_pico(disk)?
                } else {
                    let path = args.get_one::<String>("PICO_PATH").unwrap().to_string();
                    wait_for_path(Path::new(&path));
                    path
                };
                path.push_str("/fw.uf2");
                fs::write(path, include_bytes!("resources/extender.uf2"))
                    .map_err(AppError::IoError)?;
            }
            _ => {}
        },
        _ => {}
    }

    Ok(())
}

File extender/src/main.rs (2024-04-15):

#![no_std]
#![no_main]

extern crate panic_probe;
extern crate rp2040_hal as hal;
extern crate rtic;

use defmt_rtt as _;

mod upico;

use cortex_m::singleton;
use hal::adc;
use hal::gpio::*;
use hal::pac;
use hal::pio::{PIOBuilder, PIOExt};
use hal::timer::{monotonic::Monotonic, *};
use hal::usb::UsbBus;
use pio::Assembler;
use upico::*;
use usb_device::class_prelude::*;
use usb_device::prelude::*;

#[link_section = ".boot2"]
#[no_mangle]
#[used]
pub static BOOT2: [u8; 256] = rp2040_boot2::BOOT_LOADER_GENERIC_03H;

pub const XTAL_FREQ_HZ: u32 = 12_000_000_u32;

#[rtic::app(device = pac, peripherals = true, dispatchers = [SW0_IRQ, SW1_IRQ])]
mod app {
    use super::*;

    #[monotonic(binds = TIMER_IRQ_0, default = true)]
    type Oracle = Monotonic<Alarm0>;

    #[local]
    struct Local {
        upico: UpicoClass,
        usb_dev: UsbDevice<'static, hal::usb::UsbBus>,
    }

    #[shared]
    struct Shared {}

    #[init]
    fn init(ctx: init::Context) -> (Shared, Local, init::Monotonics) {
        let mut resets = ctx.device.RESETS;
        let mut watchdog = hal::Watchdog::new(ctx.device.WATCHDOG);
        let clocks = hal::clocks::init_clocks_and_plls(
            XTAL_FREQ_HZ,
            ctx.device.XOSC,
            ctx.device.CLOCKS,
            ctx.device.PLL_SYS,
            ctx.device.PLL_USB,
            &mut resets,
            &mut watchdog,
        )
        .ok()
        .expect("Clocks init failed");

        let mut timer = hal::Timer::new(ctx.device.TIMER, &mut resets, &clocks);
        let alarm = timer.alarm_0().expect("Alarm0 init failed");
        let mono = Monotonic::new(timer, alarm);

        let sio = hal::Sio::new(ctx.device.SIO);
        let pins = Pins::new(
            ctx.device.IO_BANK0,
            ctx.device.PADS_BANK0,
            sio.gpio_bank0,
            &mut resets,
        );
        let led = pins.gpio25.into_push_pull_output();
        let adc = adc::Adc::new(ctx.device.ADC, &mut resets);
        let adc_pins = (
            adc::AdcPin::new(pins.gpio26),
            adc::AdcPin::new(pins.gpio27),
            adc::AdcPin::new(pins.gpio28),
            adc::AdcPin::new(pins.gpio29),
        );

        pins.gpio0.into_function::<FunctionPio0>();
        pins.gpio1.into_function::<FunctionPio0>();
        pins.gpio2.into_function::<FunctionPio0>();
        pins.gpio3.into_function::<FunctionPio0>();
        pins.gpio4.into_function::<FunctionPio0>();
        pins.gpio5.into_function::<FunctionPio0>();
        pins.gpio6.into_function::<FunctionPio0>();
        pins.gpio7.into_function::<FunctionPio0>();
        pins.gpio8.into_function::<FunctionPio0>();
        pins.gpio9.into_function::<FunctionPio0>();
        pins.gpio10.into_function::<FunctionPio0>();
        pins.gpio11.into_function::<FunctionPio0>();
        pins.gpio12.into_function::<FunctionPio0>();
        pins.gpio13.into_function::<FunctionPio0>();
        pins.gpio14.into_function::<FunctionPio0>();
        pins.gpio15.into_function::<FunctionPio0>();

        let mut asm = Assembler::new();
        let mut wrap_target = asm.label();
        let mut wrap_source = asm.label();
        asm.bind(&mut wrap_target);
        asm.out(pio::OutDestination::EXEC, 32);
        asm.bind(&mut wrap_source);
        let (mut pio, sm, _, _, _) = ctx.device.PIO0.split(&mut resets);
        let program = pio.install(&asm.assemble_program()).unwrap();
        let (sm, rx, tx) = PIOBuilder::from_program(program)
            .autopull(true)
            .autopush(true)
            .pull_threshold(32)
            .push_threshold(32)
            .in_pin_base(0)
            .out_pins(0, 16)
            .build(sm);
        sm.start();

        let usb_regs = ctx.device.USBCTRL_REGS;
        let usb_dpram = ctx.device.USBCTRL_DPRAM;
        let usb_bus = UsbBus::new(usb_regs, usb_dpram, clocks.usb_clock, true, &mut resets);
        let usb_bus: &'static UsbBusAllocator<UsbBus> =
            singleton!(: UsbBusAllocator<UsbBus> = UsbBusAllocator::new(usb_bus))
                .expect("USB init failed");

        let upico = UpicoClass::new(usb_bus, rx, tx, adc, adc_pins, led);
        let usb_dev = UsbDeviceBuilder::new(usb_bus, UsbVidPid(0x1209, 0xbc07))
            .manufacturer("vitaly.codes")
            .product("uPico GPIO Extender")
            .build();
        unsafe {
            pac::NVIC::unmask(pac::Interrupt::USBCTRL_IRQ);
        };

        (Shared {}, Local { upico, usb_dev }, init::Monotonics(mono))
    }

    #[task(binds = USBCTRL_IRQ, local = [usb_dev, upico])]
    fn usb_irq(ctx: usb_irq::Context) {
        ctx.local.usb_dev.poll(&mut [ctx.local.upico]);
    }
}

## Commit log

2023-08-13 aux routing
    [upico.kicad_pcb, upico.kicad_sch]
2023-08-13 power routing
    [upico.kicad_pcb, upico.kicad_sch]
2023-10-07 control app
    [upico.kicad_pcb, upico.kicad_sch]
2023-10-10 add BOM
    [upico.kicad_pcb, upico.kicad_sch]
2023-10-11 control app refactoring
    [cover.scad, cover.stl, upico.kicad_pcb]
2023-10-11 update cover
    [cover.scad, cover.stl]
2023-10-12 change USB connector
    [upico.kicad_pcb, upico.kicad_sch]
2023-10-14 update pcb
    [upico.kicad_pcb, upico.kicad_sch]
2023-10-18 switch from gpiocdev to wiring pi
2023-10-25 invert power control signals
    [upico.kicad_pcb, upico.kicad_sch]
2023-10-28 fix typo
    [upico.kicad_pcb]
2023-10-28 update docs
    [cover.scad, cover.stl]
2023-11-01 pico auto mount
    [upico.kicad_sch]
2023-11-23 pico disc auto discovery
2024-04-14 gpio extender
    [upico.kicad_pcb, upico.kicad_sch]
2024-04-15 extender led
2024-04-17 shell completions
    [upico.kicad_pcb]
2024-05-09 generalize mount path
